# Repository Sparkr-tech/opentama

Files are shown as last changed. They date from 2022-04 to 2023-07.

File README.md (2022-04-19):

# OpenTama - An open-source reference design for MCUGotchi

## Synopsis

OpenTama is an open-source development board serving educational purposes, specifically designed for [MCUGotchi](https://github.com/jcrona/mcugotchi/) using [KiCad](https://www.kicad.org/).

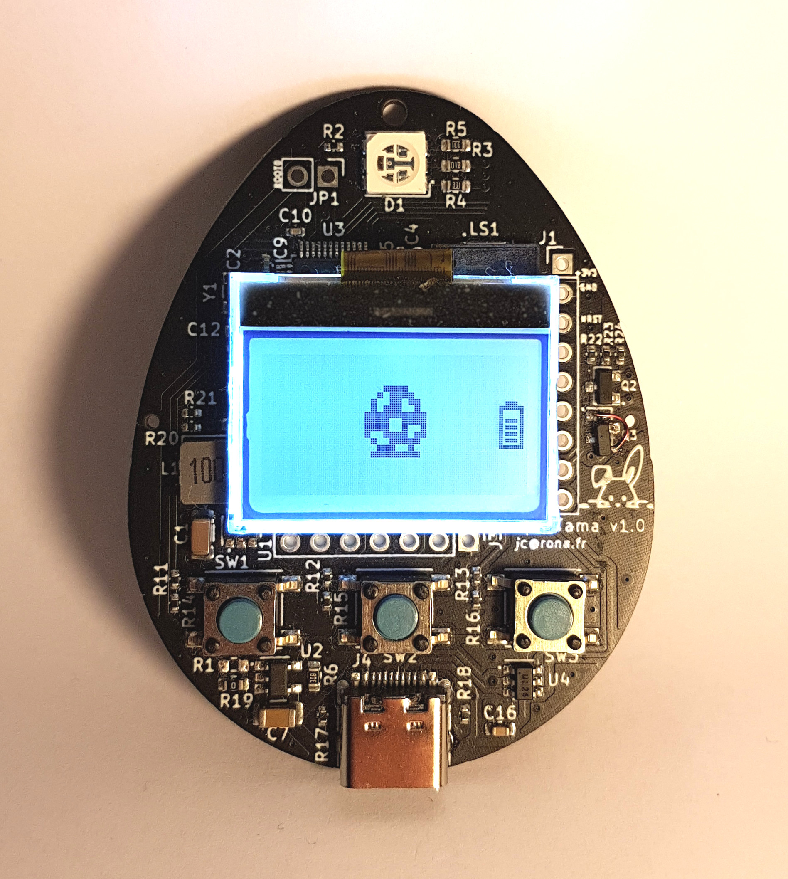
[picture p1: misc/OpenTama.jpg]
OpenTama board


It features:
* a low-power STM32L072CBT MCU
* either a backlit 128x64 LCD UC1701x or a 128x64 OLED SSD1306 display
* an RGB LED for notifications
* a piezoelectric speaker
* a 1000mAh battery
* a USB C connector for data and charging
* three buttons

Being an open-source hardware design, anyone can manufacture his/her own board. Furthermore, all components have been placed on the top side of the board, so that the assembly as well can be performed by EMS such as JLCPCB, even for small quantities. The battery and screen must be soldered manually.

## Build instructions
### Hardware

1. Make or buy an OpenTama board

	If you decide to build it, please note that the JLCPCB references for all the components have already been provided in the project. However, those have been selected depending on their availability at a specific point in time, and will probably need adjustments if you decide to go with JLCPCB.

2. Decide if you want an SSD1306 OLED screen or a UC1701x LCD screen, and buy it

	The UC1701x LCD is a low power display compared to the SSD1306 OLED that drains way more power. However, if you plan to use the MCUGotchi firmware, the highest power consumption will come from the MCU that will not really have time to sleep, so your choice will not have a big impact on the overall power consumption.

	If you want to use an SSD1306, the board expects a regular 7-pin 0,96" integrated module. However, if you want a UC1701x, you just need the LCD itself, and you can either choose an FPC one (0.5mm pitch, 14 pins), or one that needs to be soldered (0.6mm pitch, 14 pins).  
For reference, we used [this one](https://www.aliexpress.com/item/32828607106.html).

3. Buy a a battery

	The design has been made assuming a 1000mAh 40x30x12mm Li-Po/Li-ion battery.  
For reference, we used [this one](https://www.aliexpress.com/item/4000742443431.html).

4. Plug or solder the display

5. Solder the battery

6. Your OpenTama board is ready !

### Software
1. Build the firmware of your choosing

	For instance, checkout the [MCUGotchi](https://github.com/jcrona/mcugotchi/) repository and follow the instructions to build it for the OpenTama board.

2. Get and build [dfu-util](http://dfu-util.sourceforge.net/)

3. Boot the board in DFU mode

	Close the BOOT0 jumper at the top of the board, and while doing so, trigger a reset by connecting together the NRST and GND pins at the right of the board.

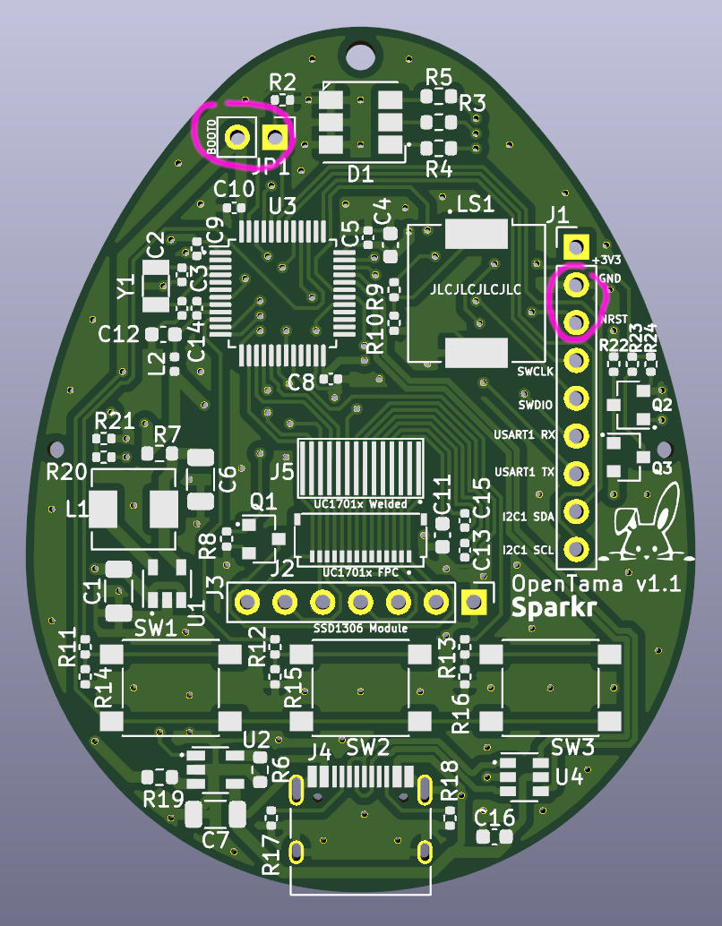
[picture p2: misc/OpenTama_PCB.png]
OpenTama board


4. Program the board using __dfu-util__
```
$ cd mcugotchi
$ sudo make flash
```
or
```
$ sudo dfu-util -a 0 -s 0x08000000:leave -D <firmware.bin>
```

5. Enjoy !

## License

OpenTama is distributed under the CERN-OHL-S v2 license. See the LICENSE file for more information.

__  
Copyright (C) 2022 Sparkr

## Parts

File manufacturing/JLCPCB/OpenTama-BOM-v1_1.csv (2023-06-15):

Comment | Designator | Footprint | JLCPCB Part #
Battery_Cell | BT1 | OpenTama:Battery_Pads_4x4
4.7uF | C1 | Capacitor_SMD:C_1206_3216Metric | C29823
330nF/25V | C11 | Capacitor_SMD:C_0603_1608Metric | C1615
1uF | C12 | Capacitor_SMD:C_0603_1608Metric | C15849
2.2uF/5V | C13,C15 | Capacitor_SMD:C_0402_1005Metric | C12530
10nF | C14 | Capacitor_SMD:C_0402_1005Metric | C15195
100nF | C16 | Capacitor_SMD:C_0603_1608Metric | C14663
12pF | C2,C3 | Capacitor_SMD:C_0402_1005Metric | C1547
10uF | C4 | Capacitor_SMD:C_0603_1608Metric | C19702
100nF | C5,C8,C9,C10 | Capacitor_SMD:C_0402_1005Metric | C1525
10uF | C6 | Capacitor_SMD:C_1206_3216Metric | C13585
1uF | C7 | Capacitor_SMD:C_1206_3216Metric | C1848
LED_RGB | D1 | OpenTama:LED_RGB_TC5050 | C784540
Conn_01x09 | J1 | Connector_PinHeader_2.54mm:PinHeader_1x09_P2.54mm_Vertical
Conn_01x14 | J2 | OpenTama:Hirose_FH34SRJ-14S-0.5SH_1x14-1MP_P0.50mm_Horizontal | C324724
Conn_01x07 | J3 | Connector_PinHeader_2.54mm:PinHeader_1x07_P2.54mm_Vertical
USB_C_Receptacle_USB2.0 | J4 | Connector_USB:USB_C_Receptacle_HRO_TYPE-C-31-M-12 | C165948
BOOT0 | JP1 | Connector_PinHeader_2.54mm:PinHeader_1x02_P2.54mm_Vertical
No BATT | JP2 | Jumper:SolderJumper-2_P1.3mm_Open_RoundedPad1.0x1.5mm
10uH | L1 | Inductor_SMD:L_Sunlord_MWSA0518_5.4x5.2mm | C408412
39nH | L2 | Inductor_SMD:L_0402_1005Metric | C26443
Speaker_Crystal | LS1 | Buzzer_Beeper:Buzzer_CUI_CPT-9019S-SMT | C391035
BSS138 | Q1,Q2 | Package_TO_SOT_SMD:SOT-23 | C347484
BSS84 | Q3 | Package_TO_SOT_SMD:SOT-23 | C8492
1k | R10 | Resistor_SMD:R_0402_1005Metric | C11702
330 | R11,R12,R13 | Resistor_SMD:R_0402_1005Metric | C25104
220k | R14,R15,R16 | Resistor_SMD:R_0402_1005Metric | C25767
5.1k | R17,R18 | Resistor_SMD:R_0402_1005Metric | C25905
10k | R2,R8 | Resistor_SMD:R_0402_1005Metric | C25744
100k | R22 | Resistor_SMD:R_0402_1005Metric | C25741
20k | R20,R21,R23,R24 | Resistor_SMD:R_0402_1005Metric | C25765
1k | R3 | Resistor_SMD:R_0603_1608Metric | C21190
330 | R4,R5 | Resistor_SMD:R_0603_1608Metric | C23138
2k 1% | R6 | Resistor_SMD:R_0603_1608Metric | C22975
0 | R7,R19 | Resistor_SMD:R_0603_1608Metric | C21189
100 | R9 | Resistor_SMD:R_0402_1005Metric | C25076
LEFT | SW1 | Button_Switch_SMD:SW_Push_1P1T_NO_6x6mm_H9.5mm | C221880
MIDDLE | SW2 | Button_Switch_SMD:SW_Push_1P1T_NO_6x6mm_H9.5mm | C221880
RIGHT | SW3 | Button_Switch_SMD:SW_Push_1P1T_NO_6x6mm_H9.5mm | C221880
TPS62203DBV | U1 | Package_TO_SOT_SMD:SOT-23-5 | C9051
LTC4054ES5-4.2 | U2 | Package_TO_SOT_SMD:TSOT-23-5 | C462648
STM32L072CBTx | U3 | Package_QFP:LQFP-48_7x7mm_P0.5mm | C465977
USBLC6-2SC6 | U4 | Package_TO_SOT_SMD:SOT-23-6 | C2827654
32768Hz - 12,5 pF | Y1 | Crystal:Crystal_SMD_3215-2Pin_3.2x1.5mm | C32346

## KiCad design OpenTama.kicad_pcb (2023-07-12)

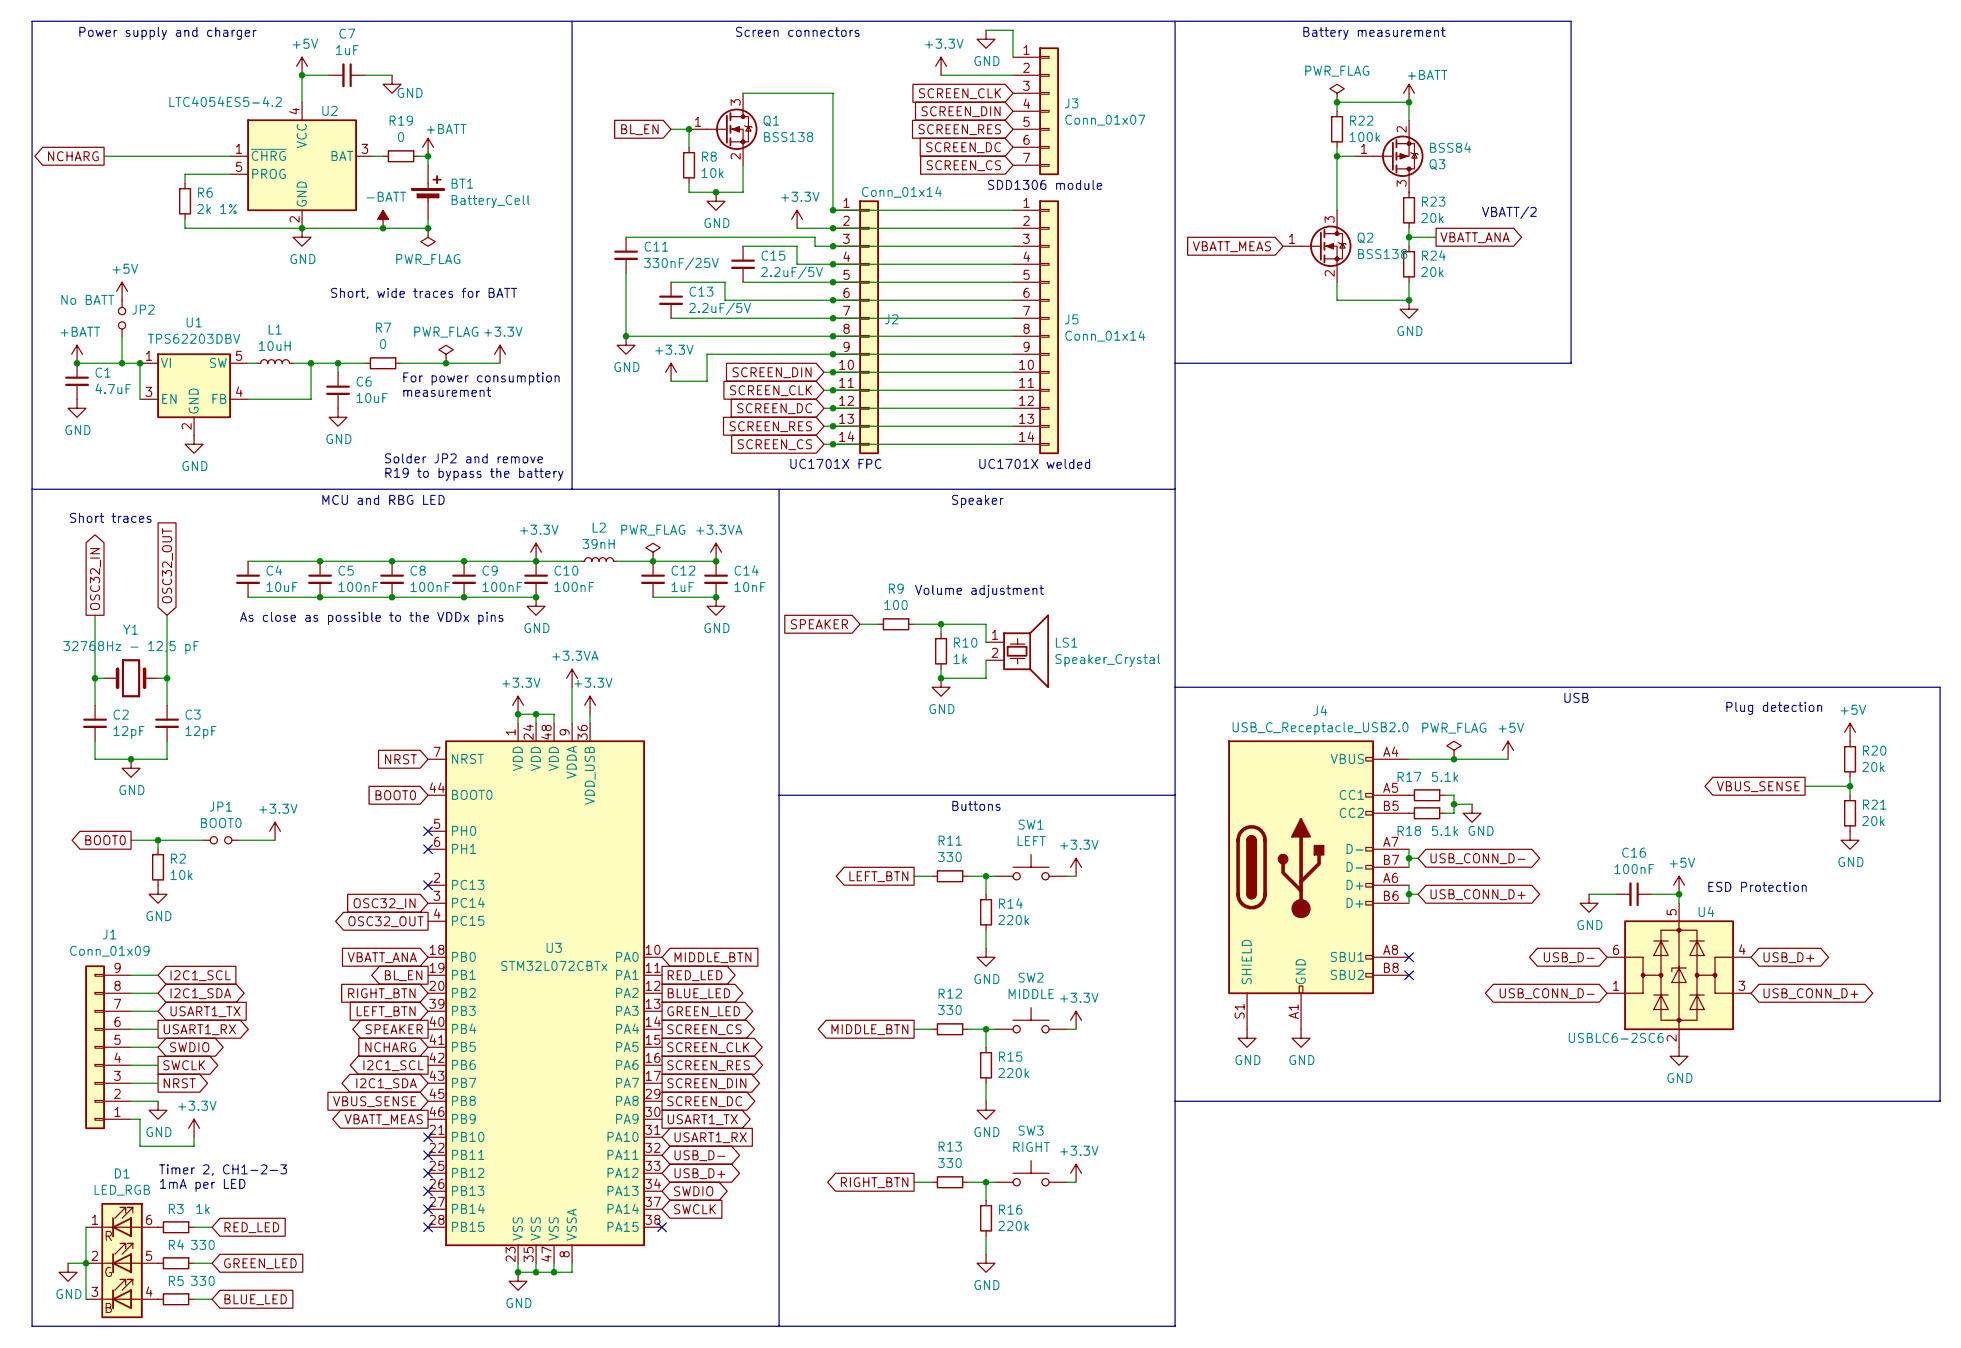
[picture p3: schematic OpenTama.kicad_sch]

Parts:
BT1: Battery_Cell; Battery_Pads_4x4
C1: 4.7uF; C_1206_3216Metric; LCSC C29823
C2, C3: 12pF; C_0402_1005Metric; LCSC C1547
C4: 10uF; C_0603_1608Metric; LCSC C19702
C5, C8, C9, C10: 100nF; C_0402_1005Metric; LCSC C1525
C6: 10uF; C_1206_3216Metric; LCSC C13585
C7: 1uF; C_1206_3216Metric; LCSC C1848
C11: 330nF/25V; C_0603_1608Metric; LCSC C1615
C12: 1uF; C_0603_1608Metric; LCSC C15849
C13, C15: 2.2uF/5V; C_0402_1005Metric; LCSC C12530
C14: 10nF; C_0402_1005Metric; LCSC C15195
C16: 100nF; C_0603_1608Metric; LCSC C14663
D1: LED_RGB; LED_RGB_TC5050; LCSC C784540
J1: Conn_01x09; PinHeader_1x09_P2.54mm_Vertical
J2: Conn_01x14; Hirose_FH34SRJ-14S-0.5SH_1x14-1MP_P0.50mm_Horizontal; LCSC C324724
J3: Conn_01x07; PinHeader_1x07_P2.54mm_Vertical
J4: USB_C_Receptacle_USB2.0; USB_C_Receptacle_HRO_TYPE-C-31-M-12; LCSC C165948
J5: Conn_01x14; LCD_14p_0.6mm
JP1: BOOT0; PinHeader_1x02_P2.54mm_Vertical
JP2: No BATT; SolderJumper-2_P1.3mm_Open_RoundedPad1.0x1.5mm
L1: 10uH; L_Sunlord_MWSA0518_5.4x5.2mm; LCSC C408412
L2: 39nH; L_0402_1005Metric; LCSC C26443
LS1: Speaker_Crystal; Buzzer_CUI_CPT-9019S-SMT; LCSC C391035
Q1, Q2: BSS138; SOT-23; LCSC C347484
Q3: BSS84; SOT-23; LCSC C8492
R2, R8: 10k; R_0402_1005Metric; LCSC C25744
R3: 1k; R_0603_1608Metric; LCSC C21190
R4, R5: 330; R_0603_1608Metric; LCSC C23138
R6: 2k 1%; R_0603_1608Metric; LCSC C22975
R7, R19: 0; R_0603_1608Metric; LCSC C21189
R9: 100; R_0402_1005Metric; LCSC C25076
R10: 1k; R_0402_1005Metric; LCSC C11702
R11, R12, R13: 330; R_0402_1005Metric; LCSC C25104
R14, R15, R16: 220k; R_0402_1005Metric; LCSC C25767
R17, R18: 5.1k; R_0402_1005Metric; LCSC C25905
R20, R21, R23, R24: 20k; R_0402_1005Metric; LCSC C25765
R22: 100k; R_0402_1005Metric; LCSC C25741
SW1: LEFT; SW_Push_1P1T_NO_6x6mm_H9.5mm; LCSC C221880
SW2: MIDDLE; SW_Push_1P1T_NO_6x6mm_H9.5mm; LCSC C221880
SW3: RIGHT; SW_Push_1P1T_NO_6x6mm_H9.5mm; LCSC C221880
U1: TPS62203DBV; SOT-23-5; LCSC C9051
U2: LTC4054ES5-4.2; TSOT-23-5; LCSC C462648
U3: STM32L072CBTx; LQFP-48_7x7mm_P0.5mm; LCSC C465977
U4: USBLC6-2SC6; SOT-23-6; LCSC C2827654
Y1: 32768Hz - 12,5 pF; Crystal_SMD_3215-2Pin_3.2x1.5mm; LCSC C32346

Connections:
+3.3VA: C12.1, C14.1, L2.2, U3.9 (VDDA)
+3V3: C4.1, C5.1, C8.1, C9.1, C10.1, J1.1, J2.2, J2.9, J3.2, J5.2, J5.9, JP1.2, L2.1, R7.1, SW1.2, SW2.2, SW3.2, U3.1 (VDD), U3.24 (VDD), U3.36 (VDD_USB), U3.48 (VDD)
+5V: C7.2, C16.1, J4.A4 (VBUS), J4.A9 (VBUS), J4.B4 (VBUS), J4.B9 (VBUS), JP2.1, R20.1, U2.4 (VCC), U4.5 (VBUS)
+BATT: BT1.1 (+), C1.1, JP2.2, Q3.2 (S), R19.1, R22.1, U1.1 (VI), U1.3 (EN)
-BATT: BT1.2 (-), C1.2, C2.2, C3.2, C4.2, C5.2, C6.2, C7.1, C8.2, C9.2, C10.2, C11.2, C12.2, C14.2, C16.2, D1.1 (RK), D1.2 (GK), D1.3 (BK), J1.2, J2.8, J3.1, J4.A1 (GND), J4.A12 (GND), J4.B1 (GND), J4.B12 (GND), J4.S1 (SHIELD), J5.8, LS1.2, Q1.2 (S), Q2.2 (S), R2.2, R6.2, R8.2, R10.2, R14.2, R15.2, R16.2, R17.1, R18.1, R21.2, R24.2, U1.2 (GND), U2.2 (GND), U3.8 (VSSA), U3.23 (VSS), U3.35 (VSS), U3.47 (VSS), U4.2 (GND)
BLUE_LED: R5.1, U3.12 (PA2)
BL_EN: Q1.1 (G), R8.1, U3.19 (PB1)
BOOT0: JP1.1, R2.1, U3.44 (BOOT0)
GREEN_LED: R4.1, U3.13 (PA3)
I2C1_SCL: J1.9, U3.42 (PB6)
I2C1_SDA: J1.8, U3.43 (PB7)
LEFT_BTN: R11.2, U3.39 (PB3)
MIDDLE_BTN: R12.2, U3.10 (PA0)
NCHARG: U2.1 (~CHRG), U3.41 (PB5)
NRST: J1.3, U3.7 (NRST)
unnamed: D1.4 (BA), R5.2
unnamed: D1.5 (GA), R4.2
unnamed: D1.6 (RA), R3.2
unnamed: J2.1, J5.1, Q1.3 (D)
unnamed: C11.1, J2.3, J5.3
unnamed: C15.1, J2.4, J5.4
unnamed: C15.2, J2.5, J5.5
unnamed: C13.1, J2.6, J5.6
unnamed: C13.2, J2.7, J5.7
unnamed: J4.A5 (CC1), R17.2
unnamed: J4.B5 (CC2), R18.2
unnamed: LS1.1, R9.1, R10.1
unnamed: Q2.3 (D), Q3.1 (G), R22.2
unnamed: Q3.3 (D), R23.1
unnamed: R11.1, R14.1, SW1.1
unnamed: R12.1, R15.1, SW2.1
unnamed: R13.1, R16.1, SW3.1
unnamed: C6.1, L1.2, R7.2, U1.4 (FB)
unnamed: L1.1, U1.5 (SW)
unnamed: R19.2, U2.3 (BAT)
unnamed: R6.1, U2.5 (PROG)
OSC32_IN: C2.1, U3.3 (PC14), Y1.1
OSC32_OUT: C3.1, U3.4 (PC15), Y1.2
RED_LED: R3.1, U3.11 (PA1)
RIGHT_BTN: R13.2, U3.20 (PB2)
SCREEN_CLK: J2.11, J3.3, J5.11, U3.15 (PA5)
SCREEN_CS: J2.14, J3.7, J5.14, U3.14 (PA4)
SCREEN_DC: J2.12, J3.6, J5.12, U3.29 (PA8)
SCREEN_DIN: J2.10, J3.4, J5.10, U3.17 (PA7)
SCREEN_RES: J2.13, J3.5, J5.13, U3.16 (PA6)
SPEAKER: R9.2, U3.40 (PB4)
SWCLK: J1.4, U3.37 (PA14)
SWDIO: J1.5, U3.34 (PA13)
USART1_RX: J1.6, U3.31 (PA10)
USART1_TX: J1.7, U3.30 (PA9)
USB_CONN_D+: J4.A6 (D+), J4.B6 (D+), U4.3 (I/O2)
USB_CONN_D-: J4.A7 (D-), J4.B7 (D-), U4.1 (I/O1)
USB_D+: U3.33 (PA12), U4.4 (I/O2)
USB_D-: U3.32 (PA11), U4.6 (I/O1)
VBATT_ANA: R23.2, R24.1, U3.18 (PB0)
VBATT_MEAS: Q2.1 (G), U3.46 (PB9)
VBUS_SENSE: R20.2, R21.1, U3.45 (PB8)

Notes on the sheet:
Power supply and charger
Solder JP2 and remove R19 to bypass the battery
Short traces
ESD Protection
Short, wide traces for BATT
Battery measurement
VBATT/2
Speaker
USB
Timer 2, CH1-2-3 1mA per LED
As close as possible to the VDDx pins
Plug detection
SDD1306 module
MCU and RBG LED
For power consumption measurement
UC1701X FPC
UC1701X welded
Volume adjustment
Screen connectors
Buttons

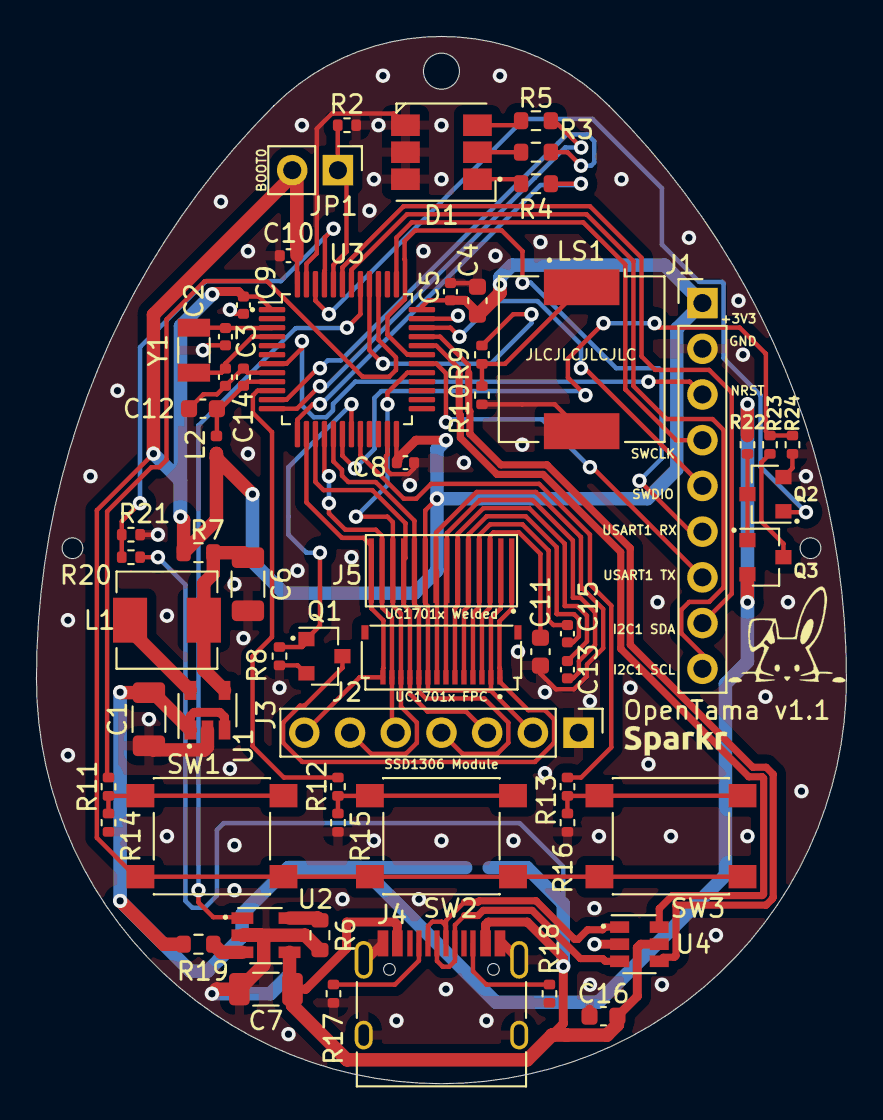
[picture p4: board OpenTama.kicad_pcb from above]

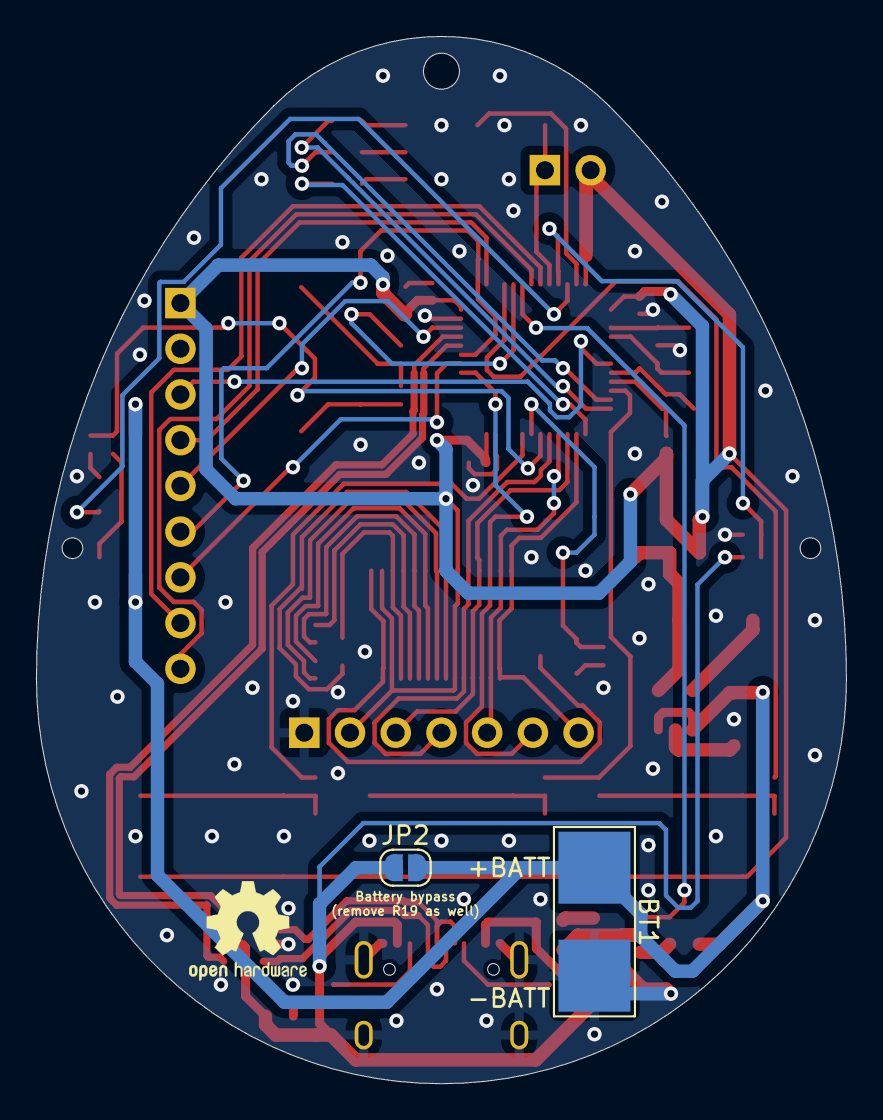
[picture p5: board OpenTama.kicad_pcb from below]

Board: 2 copper layers, 45.0 x 58.2 mm, 62 parts (2 on the bottom side), 57 nets.

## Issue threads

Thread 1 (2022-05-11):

Create github release with Gerber/BOM files

kabili207, 2022-05-11:
Can you create a github release that includes the gerbers, BOM, and pos/cpl files that you generated? I tried making an order through JLCPCB and many of the components shown on the SMT assembly preview seem to have random rotations (regardless of which plugin or script I use). Some are 90 degrees off, others are 180 off.

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

jcrona, 2022-05-12:
Hi !
Actually, we have those files for the v1.0 revision only, not for the v1.1 (that has not been actually produced yet). However, we had the exact same issue, which is caused by the fact that the manufacturer (JLCPCB in this case) and KiCAD do not use the same 0° reference.
The only way to deal with that is to fix the POS file manually, which is pretty straightforward (the penultimate column of the CSV file is the angle from 0.0 to 270.0). You will not be able to fix the USB C connector yourself, but JLCPCB will do it for you and ask you to validate (along with any remaining issue, since all the proper indications are printed on the PCB).

jcrona, 2022-05-12:
Please also carefully verify that every part selected by JLCPCB does match the one expected, especially the value of the resistors and capacitors.

meelix, 2022-12-18:
An update to this would be much appreciated

jcrona, 2023-02-06:
Hi @meelix, what update would you need ?

meelix, 2023-02-06:
Providing BOM and pos files of the most recent version as a downloadable release.

So people who know nothing about pcbs and circuits can still get a copy.

Right now you have to learn which software to use just just to open the files. Then you have to figure out how to upload it to jlcpcb, which is a  big hassle because the documentation is terrible/non existent, there are at least 3 ways to export it and neither of them work until you figure out you can just use the pretty well hidden and unmentioned plugin store (to find a plugin that exports it with wrong rotations).
If Jlcpcb has any questions I'm completely unable to answer them.

All of this could be avoided if there where fixed files to grab and upload. Thank you.

kabili207, 2023-02-06:
> Providing BOM and pos files of the most recent version as a downloadable release.
This is mainly what I would like as well. At the time I created this issue JLCPCB was out of stock of the main MCU and I had no idea which of the variations that they *did* have in stock at the time would be compatible without combing through the datasheets.

> you can just use the pretty well hidden and unmentioned plugin store (to find a plugin that exports it with wrong rotations).

I started work on modifying one of those plugins to read rotations from the component fields rather than arbitrarily applying a static rotation value, but I stopped when I ran into the out-of-stock problem mentioned above.

BabyFnord, 2023-02-22:
> So people who know nothing about pcbs and circuits can still get a copy.

Chiming in here in full ack of @kabili207 and @meelix. This project would clearly benefit from supplying ready-to-upload files for JLPCB, or any other supplier the project owners recommend. At least for as long as there's no other way to obtain boards than to have them made-to-order on your own.

jcrona, 2023-03-10:
Good points.
We will generate those files. However, for the pos file, it highly depends on the actual manufacturer, so we can just release something generic that will need manual review/adjustment (the manufacturer will probably do it anyway). But at least, no need to learn KiCAD.

BabyFnord, 2023-03-11:
Thank you, looking forward to that!

murdick, 2023-04-12:
+1 for this

coaxial, 2023-04-16:
Just tried to order the board on JLCPCB, uploading each file in the root for the repo. But they aren't happy with any of the files and having never used JLCPCB, I don't really know how could I order a board of my own.

Having the files that JLCPCB requires in the repo or release would be very useful to people like me :)

BabyFnord, 2023-04-16:
At this time, I would consider this project partly »abandon-ware«. No offence to the devs, really, this project is as fantastic as it is highly appreciated!, but for the majority of tech-hobbyist parents looking forward to render their kids happy and aware of Open projects, even

> something generic that will need manual review/adjustment

might be rather gatekeeping than encouraging to pick up on this. FWIW, at least I'd rather pick up on something specific (take JLPCB for a low-cost example) with a good prospect on succeeding, and judging by the few folks chiming in here, that'd be a welcomed approach. Maybe someone forking this project could ease this, if not for the devs … 🤷🏻‍♂️

kabili207, 2023-05-02:
I managed to get the board ordered and assembled through JLCPCB, as well as flashing the mcugotchi firmware, but I'm not getting anything on the screen. I'm using an SSD1306 screen ([this one](https://www.amazon.com/dp/B087CW1YLK)], to be precise) and I made sure to update the opentama board config to use it, but I'm not getting anything. It beeps if I press the buttons, the LED is pulses an orange color, but all I'm seeing is a black screen.

Is this due to the v1.1 not being production ready or an issue in mcugotchi?

BabyFnord, 2023-05-02:
> I managed to get the board ordered and assembled through JLCPCB

Were you able to verify that _every_ part selected by JLCPCB matches the one expected in _type, value_ and _position_?

kabili207, 2023-05-02:
The files uploaded to JLCPCB were generated by the [Fabrication ToolKit plugin](https://github.com/bennymeg/JLC-Plugin-for-KiCad). I did have to upgrade the project from KiCad version 5 to version 7, as well as rename the custom symbol field from JLCPCB to LCSC for every part. I also reviewed the positions generated during the order process and manually added the rotation offset (aka JlcRotOffset) to each symbol and regenerated all files until things lined up properly. I going to make a pull request with these changes in a bit.

I haven't reviewed every single component yet, so it's possible the LCSC part numbers weren't updated from v1.0 to v1.1. But considering that everything else is working, and the SSD1306 is directly connected to the mcu, I'm questioning if there's something out of date in the mcugotchi firmware or if I just ordered bad screens. Or maybe I accidentally dislodged some component while trying to solder the screen on.

I'm going to dig up my logic analyzer and see if I can determine what's going on.

Symbol properties in KiCad
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

SSD1306 part of the schematic
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

Final positions of order
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

jcrona, 2023-06-15:
Hi @kabili207 ,

Very interesting, and thx for the PR ! The board should work with an SSD1306 screen, I tested it myself.
I actually produced only v1.0 boards, but the differences with v1.1 are mainly mistakes made that had to be manually fixed on v1.0 boards, so v1.1 and fixed v1.0 boards should be exactly the same.
So, as you said, you just need to define `BOARD_HAS_SSD1306` instead of `BOARD_HAS_UC1701X` to enable it.

Just to be sure, it means you successfully uploaded the firmware to the device ?
Did you check on your SSD1306 module that it was properly configured in SPI mode ?
Did you check somehow that your SSD1306 module is actually working ?

The SSD1306 module I tested do not have a CS pin (always enabled), so maybe something is wrong in the SSD1306 driver regarding how this pin is handled ?

It has also been a long time since I tested the SSD1306 screen, you cannot rule out the possibility I broke something at a point. Maybe, try to build a MCUGotchi at https://github.com/jcrona/mcugotchi/commit/e2ddbef9cff9d3e7720337e838629fbc7c54eccf ?

jcrona, 2023-06-15:
Hi,

Regarding the release of assembly ready files, I discovered a mistake with the J2 connector that I wanted to fix before releasing anything (actually the connector is fine, but the screen that was supposed to go there, and that I never managed to source, would not have the right orientation). I never used this connector anyway, so I may just remove it.

jcrona, 2023-06-15:
Hi all,

I double checked and the J2 connector is actually fine, so I pushed the manufacturing files for JLCPCB in the repository -> https://github.com/Sparkr-tech/opentama/commit/823d69667291539f4710ba76a8e1508ee9622d7f, where other manufacturers can also be added in the future.

Closed 2023-06-15.

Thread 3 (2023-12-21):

SSD1306 not work

lz2sat, 2023-12-21:
I try to build OpenTama with SSD1306 0.96" , i edited in opentama.h i uncommented line #define BOARD_HAS_SSD1306 and commented //#define BOARD_HAS_UC1701X , build and flashed but OLED is blank .. previously i use other type display and board is working  (not been UC1701x and image was mirrored but all work).Maybe some other file need to be edited , or some previous settings remains in eeprom from old firmware?Thanks in advance and have a nice day!

lz2sat, 2023-12-22:
Moved to mcugotchi

Closed 2023-12-22.

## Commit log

2022-04-19 Initial release of the OpenTama board
    [OpenTama.kicad_pcb, OpenTama.sch]
2023-06-15 Remove exported BOM
2023-06-15 Add v1.1 manufacturing files for JLCPCB
    Those files have been fixed manually to match JLCPCB's online tool.
    [OpenTama-BOM-v1_1.csv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]
2023-07-12 Use LCSC instead of JLCPCB in symbol props
    [OpenTama.sch]
2023-07-12 Migration to KiCAD 7.0
    [OpenTama.kicad_pcb, OpenTama.kicad_sch, OpenTama.sch]
2023-07-12 Fix project (ERC)
    [OpenTama.kicad_pcb, OpenTama.kicad_sch]
2023-07-12 Add JLCRotOffset (thx kabili207)
    [OpenTama.kicad_pcb, OpenTama.kicad_sch]

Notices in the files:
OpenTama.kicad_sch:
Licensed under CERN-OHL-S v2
